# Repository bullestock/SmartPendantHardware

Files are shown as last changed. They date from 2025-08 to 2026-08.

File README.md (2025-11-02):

# Devtronic SmartPendant

This project allows controlling a grblHAL based CNC machine without a PC. It also makes work way more convenient.

This fork builds upon the original Devtronic/Nicolai Shlapunov project, which has a store here: https://devtronic.square.site/

I have no intentions to offer this version for sale, but all files are freely available. The changes compared to the original project are:

* Instead of a display with two FCC connectors this version uses a display with a single 2.54 mm pitch connector. This does mean that the pendant is a few millimetres thicker.
* The LEDs have been removed.
* Passives are 0603 instead of 0805.
* Screw terminals have been replaced with JST XH connectors.

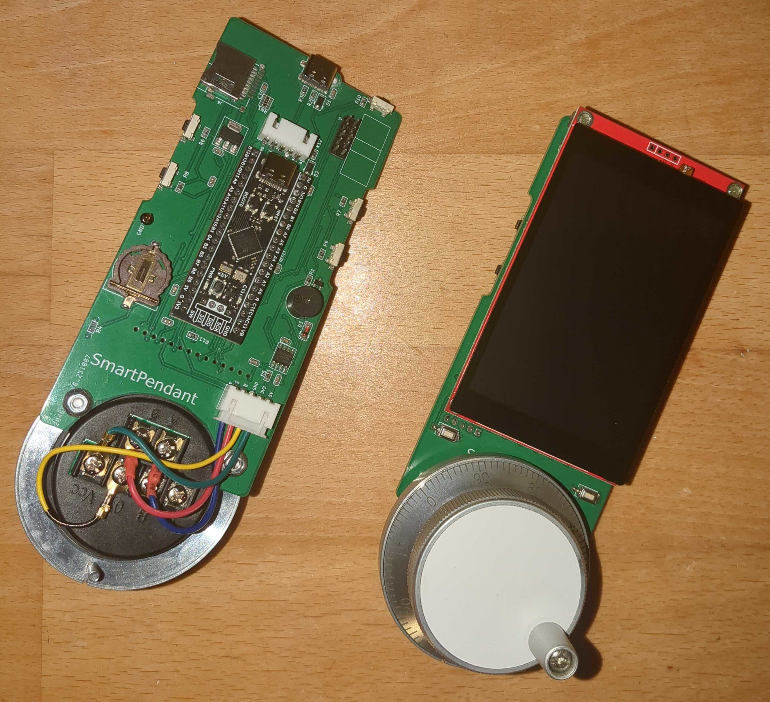
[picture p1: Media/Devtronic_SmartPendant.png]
Devtronic SmartPendant


# Firmware

Source code for this project can be found here: **https://github.com/bullestock/SmartPendantFirmware**

To load new firmware you can either use OpenOCD, or the [STM32CubeProgrammer](https://www.st.com/en/development-tools/stm32cubeprog.html).

## OpenOCD

For this you need an "ST-Link V2 mini" adapter, which can be obtained for a few dollars from AliExpress and other sites.

Connect the adapter and run this command:

    openocd -f interface/stlink.cfg -f target/stm32f4x.cfg -c "program SmartPendant.elf verify reset exit"

## STM32CubeProgrammer

Connect SmartPendant to PC using USB-C cable. Press and hold BOOT0 button, then short press NRST button, couple seconds later BOOT0 button can be released.
Open STM32CubeProgrammer. In top right corner choose "USB" from drop down list.
If field "Port" in "USB Configuration" show "No DFU detected" click update button near it.
Click "Connect" button - STM32CubeProgrammer should establish connection and show current device memory content.
Click "Open File" in left to corner, select firmware HEX file, then click "Download" button in top left corner.
When flashing is done, close STM32CubeProgrammer and short press NRST button on the Controller to restart it. 

**Note:** if flashing is successful, but firmware isn't work, check STM32CubeProgrammer log. If it says "sector 0000 does not exist" erasing operation wasn't successful and new firmware "merged"(write operation can only flip bits from 1 to 0) with old one. To fix this issue, press "eraser" button in bottom right corner and click "Ok" button in pop up window. After erasing is finished "Device memory" should show only FFFFFFFF. Flash new firmware after that. 

# Parts

To make this project yourself, you will need these essential parts:

* [WeAct BlackPill F411 25M HSE:](https://s.click.aliexpress.com/e/_DC6TlGd)
* [3.5" Display with touchscreen based on ILI9488 LCD controller and FT6236 touch controller](https://www.aliexpress.com/item/1005009339669149.html)
* [60 mm 6 pin 100 PPR handwheel](https://s.click.aliexpress.com/e/_DCFuJHr)
* [SMD connector for display](https://www.aliexpress.com/item/1005005194925318.html) (note that the connector must be aligned with the through holes, and that you need to remove the plastic part of the header on the display; see picture below).
* [Side button switches](https://www.aliexpress.com/item/1005003036287080.html)
* [Front button switches](https://www.aliexpress.com/item/1005007564864690.html)
* [USB C connector](https://www.aliexpress.com/item/1005008913274510.html)
* [Battery holder](https://www.aliexpress.com/item/4000648810345.html)
* [Buzzer](https://www.aliexpress.com/item/32949954569.html)
* The SD card footprint allows for two common sockets to be mounted.
* See the KiCAD files for additional components.

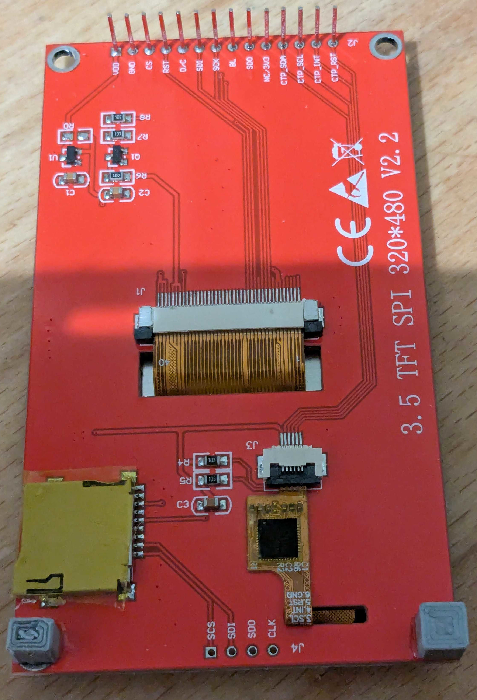
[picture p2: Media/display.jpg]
Preparing the display

Note the placement of the two display support pieces (glued to the PCB).

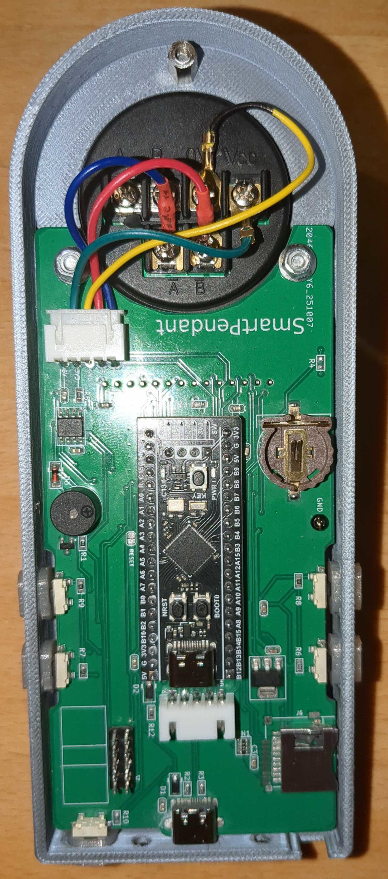
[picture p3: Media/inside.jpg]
PCB mounted in case

Note 8 mm threaded standoff on bottom encoder screw. Two printed spacers are mounted beneath the PCB.

## Case

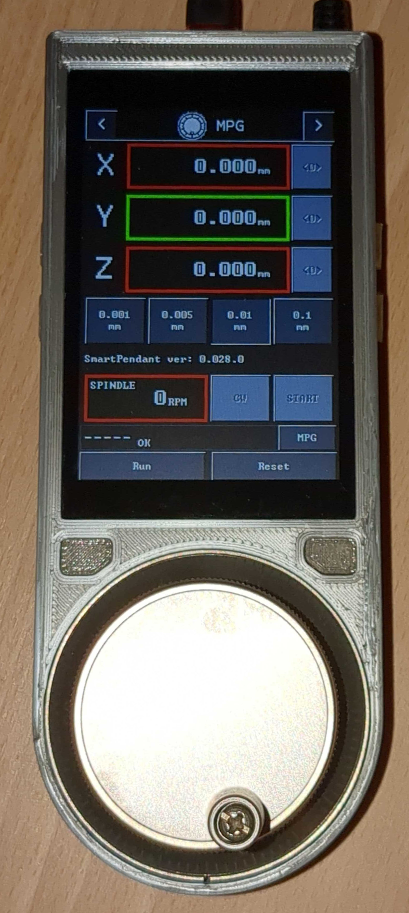
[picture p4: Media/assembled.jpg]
Assembled SmartPendant


3D_Print folder of this repo contain 3D files (OpenSCAD and STLs) of the case.

I printed the buttons in TPU filament.

## Dimensions

**160** mm x **65** mm x **24** mm (56 mm with handwheel and handle)

## Schematic

See the kicad directory.

## Firmware

Source code can be found [here](https://github.com/bullestock/SmartPendantFirmware)

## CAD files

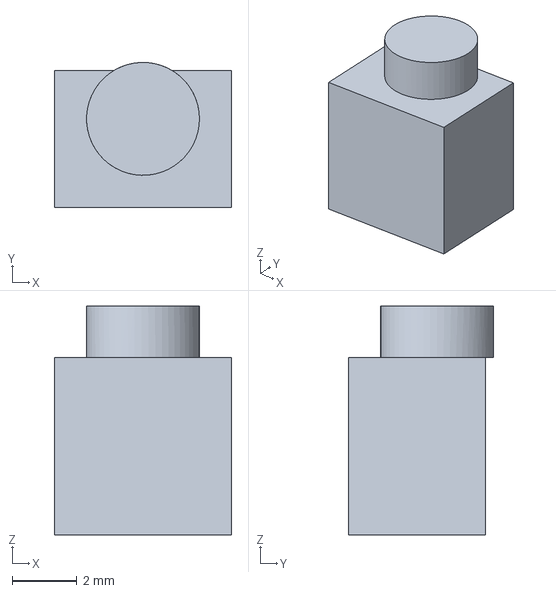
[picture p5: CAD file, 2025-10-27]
3D_Print/sp-display-spacer-2.step
5.50 x 4.50 x 7.10 mm

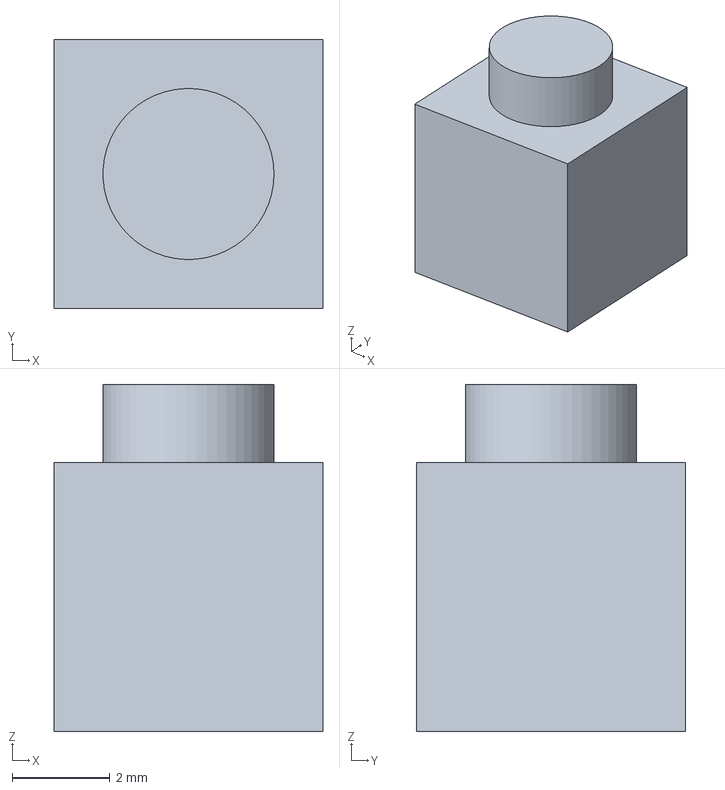
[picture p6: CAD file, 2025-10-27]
3D_Print/sp-display-spacer-1.step
5.50 x 5.50 x 7.10 mm

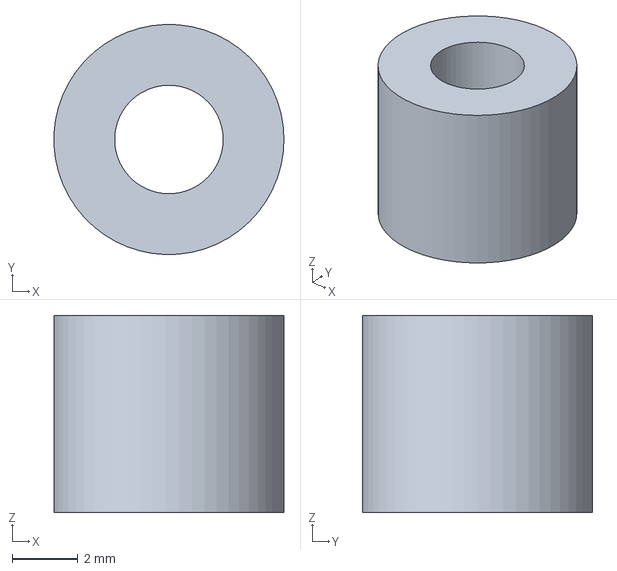
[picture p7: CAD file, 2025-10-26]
3D_Print/sp-pcb-spacer.step
6.99 x 7.00 x 6.00 mm

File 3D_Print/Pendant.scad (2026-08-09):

$fn=600;
//$fn=500;
//$fn=25;

//import("OBJ_PCB_Smart_Pendant.stl");

// Disable parts for fast update during development
FOR_PRINT = 1;
DRAW_BUTTON_HOLES = 1;
DEBUG_PORT = 0;

T = 2.4; // Case thickness
R = 2.6; // Case radius
W = 60; // Width(encoder & board)
L = 156+R*2; // Length(full length + two radiuses)
H = 20;

// Encoder tolerance
ENC_T = 0.4;

// Encoder rim height
ENC_RT = 6;

ENC_OFFSET = -5;
STANDOFF_C = 6+5.6-1.4; // For 8 mm hex standoff
BUTTON_OFFSET = -3;

BW = 60; // Board Width
BL = 126; // Board Length(from center of encoder to top edge)
BT = 1.6 + 2; // Board thickness
BZPOS = 4.4; // Board Z position if placed on table display face down
BUTZ = 7; // Button Z offset
SHZ = 8; // Screw hole Z offset

SW = 55.5; // Screen width
SH = 89.0; // Screen height
//SH = 88.8; // old
BZW = 51.5; // Bezel width
BZH = 78.0; // Bezel height
// DBL = 96; // Display Board Length

GLAND_W = 5.5;
GLAND_H = 5;

//ED = 4.2; // Distance betweeen encoder edge and screen glass
ED = BL - BW/2 - SH - (BW - SW)/2;

CP = 102.5; // MicroSD card placement

BOTTOM_H = 4; // Height of bottom piece
LOCK_H = 1.6; // Lock height


Top();
//Bottom();
//translate([75,0,0]) Bottom();
//translate([0, 0, H+BOTTOM_H]) rotate([0, 180, 0]) Bottom();

//Board();

// *******************************************************************
// ***   PCB   *******************************************************
// *******************************************************************
module PCB(H)
{
  color("purple") difference()
  {
    translate([0,0, BZPOS]) linear_extrude(height=H)
      polygon(points=[[-30,0],[-30,65],[-28.6,67.5],[-28.6,94],[-30,96.5],[-30,126],
                      [30,126],[30,96.5],[28.6,94],[28.6,67.5],[30,65],[30,0]]);
    translate([0,0,0]) cylinder(d=43, h=H);
  }
}

// *******************************************************************
// ***   Board   *****************************************************
// *******************************************************************
module Board()
{
  PCB(BT);
  translate([-57.2/2,73.2, BZPOS+BT+4]) rotate([0, 90, 0]) cylinder(d=3.5, h=57.2); // Down buttons
  translate([-57.2/2,88.3, BZPOS+BT+4]) rotate([0, 90, 0]) cylinder(d=3.5, h=57.2); // Up buttons
  // Top button
  translate([23.5,120,0])
  {
    color("black") translate([0,0.1, BZPOS+BT+4]) rotate([-90,0,0]) cylinder(d=3.5, h=5); // Up buttons
    color("silver") translate([-6.2/2,0, BZPOS+BT]) cube([6.2,4,6.2]);
  }
  // Face L buttons
  translate([23.4,28.3,0])
  {
    color("gold") translate([0,0, BZPOS-1.8]) cylinder(d=2, h=1.8); // Up buttons
    color("silver") translate([-5.08/2,-5.08/2, BZPOS-1.4]) cube([5.08,5.08,1.4]);
  }
  // Face R buttons
  translate([-23.5,28.4,0])
  {
    color("gold") translate([0,0, BZPOS-1.8]) cylinder(d=2, h=1.8); // Up buttons
    color("silver") translate([-5.08/2,-5.08/2, BZPOS-1.4]) cube([5.08,5.08,1.4]);
  }
}

// *******************************************************************
// ***   SideButtonRing   ********************************************
// *******************************************************************
module SideButtonRing(DO, DI, L, H)
{
  difference()
  {
    hull()
    {
      translate([-H/2,-L/2,0]) rotate([0, 90, 0]) cylinder(d=DO, h=H); // Up buttons
      translate([-H/2,+L/2,0]) rotate([0, 90, 0]) cylinder(d=DO, h=H); // Up buttons
    }
    hull()
    {
      translate([-H/2-1,-L/2,0]) rotate([0, 90, 0]) cylinder(d=DI, h=H+2); // Up buttons
      translate([-H/2-1,+L/2,0]) rotate([0, 90, 0]) cylinder(d=DI, h=H+2); // Up buttons
    }
  }
}

// *******************************************************************
// ***   Rotate functions   ******************************************
// *******************************************************************
function RotateX(X, Y, A) = X*cos(A) + Y*sin(A);
function RotateY(X, Y, A) = X*sin(A) + Y*cos(A);

// *******************************************************************
// ***   Button Hole   ***********************************************
// *******************************************************************
module ButtonHole(DFG, D)
{
    // Left button hole
    difference()
    {
        H = 3;
        R = W/2+H+D/2;

        BUTTON_LEN = 4.2;

        Y1 = (W/2+BUTTON_LEN-DFG) - ((W/2+BUTTON_LEN-DFG)-28.3)*2 + D/2; // Find symmetrical bottom distance
        X1 = sqrt(abs(Y1*Y1 - R*R));
        X2 = SW/2 - (SW/2-23.4)*2;// + D/2;
        Y2 = sqrt(abs(X2*X2 - R*R));
        
        hull()
        {
            // slanted corners
            translate([X1, Y1, -0.1]) cylinder(d=D, h=20);
            translate([X2, Y2, -0.1]) cylinder(d=D, h=20);
            // top right angle corner
            translate([SW/2-D/2, Y1, -0.1]) cylinder(d=D, h=20);
            // bottom corners
            translate([SW/2-D/2, W/2+BUTTON_LEN-DFG-D/2 + 0.8, -0.1]) cylinder(d=D, h=20);
            translate([X2, W/2+BUTTON_LEN-DFG-D/2 + 0.8, -0.1]) cylinder(d=D, h=20);
        }
        translate([0,0,-0.2]) cylinder(d=W+H*2, h=20);
    }
}
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

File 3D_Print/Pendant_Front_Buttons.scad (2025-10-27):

$fn = 600;

// First parameter - corner radius. It can be less than original one for clearence.
// Second parameter - Radius for lock, it may be greater than original
// Third parameter - length reduction(added to clearence gained by smaller first parameter)
translate([-15, 0, 0]) FrontButton(2.5, 3.6, 0.3);
mirror([1, 0, 0]) translate([-15, 0, 0]) FrontButton(2.5, 3.6, 0.3);

//Jig(2.5, 3.6, 0.3, 30);

// *******************************************************************
// ***   Button Hole   ***********************************************
// *******************************************************************
module FrontButton(DB, DL, LR)
{
  // All parameters from Pendant
  DFG = 2.8;
  D = 3;
  SW = 55.3; // Screen width
  SH = 88.9; // Screen height
  BW = 60; // Board Width
  BL = 126; // Board Length(from center of encoder to top edge)
  ED = BL - BW/2 - SH - (BW - SW)/2;
  W = 60; // Width(encoder & board)
  T = 2.4; // Case thickness
  
  H = 3;
  R = W/2+H+D/2;

  Y1 = (W/2+ED-DFG) - ((W/2+ED-DFG)-28.3)*2 + D/2; // Find symmetrical bottom distance
  X1 = sqrt(abs(Y1*Y1 - R*R));
  X2 = SW/2 - (SW/2-23.4)*2;// + D/2;
  Y2 = sqrt(abs(X2*X2 - R*R));

  skirt_h = 5.4 - 0.8;
  BH = skirt_h + 4.6 + 0.8;
  difference()
  {
    hull()
    {
      translate([X1-0.8, Y1, -0.1]) cylinder(d=DB, h=BH);
      translate([X2, Y2-0.5, -0.1]) cylinder(d=DB, h=BH);
      translate([SW/2-D/2 - LR + 0.3, Y1, -0.1]) cylinder(d=DB, h=BH);
      translate([SW/2-D/2 - LR + 0.3, W/2+ED-DFG-D/2,-0.1]) cylinder(d=DB, h=BH);
      translate([X2, W/2+ED-DFG-D/2, -0.1]) cylinder(d=DB, h=BH);
    }
  }
  difference()
  {
    hull()
    {
      translate([X1 - 1, Y1, -0.1]) cylinder(d=DL, h=skirt_h);
      translate([X2, Y2 - 0.5, -0.1]) cylinder(d=DL, h=skirt_h);
      translate([SW/2-D/2 - LR + 0.5,Y1,-0.1]) cylinder(d=DL, h=skirt_h);
      translate([SW/2-D/2 - LR + 0.5, W/2+ED-DFG-D/2,-0.1]) cylinder(d=DL, h=skirt_h);
      translate([X2,W/2+ED-DFG-D/2,-0.1]) cylinder(d=DL, h=skirt_h);
    }
  }
}

// *******************************************************************
// ***   Button Hole   ***********************************************
// *******************************************************************
module Jig(DB, DL, LR, HEIGHT)
{
  // All parameters from Pendant
  DFG = 2.8;
  D = 3;
  SW = 55.3; // Screen width
  SH = 88.9; // Screen height
  BW = 60; // Board Width
  BL = 126; // Board Length(from center of encoder to top edge)
  ED = BL - BW/2 - SH - (BW - SW)/2;
  W = 60; // Width(encoder & board)
  T = 2.4; // Case thickness
  
  H = 3;
  R = W/2+H+D/2;

  Y1 = (W/2+ED-DFG) - ((W/2+ED-DFG)-28.3)*2 + D/2; // Find symmetrical bottom distance
  X1 = sqrt(abs(Y1*Y1 - R*R));
  X2 = SW/2 - (SW/2-23.4)*2;// + D/2;
  Y2 = sqrt(abs(X2*X2 - R*R));

  difference()
  {
    hull()
    {
      translate([X1,Y1,-0.1]) cylinder(d=DB, h=HEIGHT);
      translate([X2,Y2,-0.1]) cylinder(d=DB, h=HEIGHT);
      translate([SW/2-D/2 - LR,Y1,-0.1]) cylinder(d=DB, h=HEIGHT);
      translate([SW/2-D/2 - LR,W/2+ED-DFG-D/2,-0.1]) cylinder(d=DB, h=HEIGHT);
      translate([X2,W/2+ED-DFG-D/2,-0.1]) cylinder(d=DB, h=HEIGHT);
    }
    translate([0,0,-0.2]) cylinder(d=W+H*2+(D-DB), h=H+0.4);
  }
}

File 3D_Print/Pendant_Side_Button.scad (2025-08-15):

$fn = 600;

SideButton(9.7, 5.6, 6.5); // 1
//SideButton(9, 5.4, 6.5); // 2

//Jig(9.2, 5.6, 6.5, 30);

// *******************************************************************
// ***   SideButton module   *****************************************
// *******************************************************************
module SideButton(L, DB, DL)
{
  // Total height
  BH = 6;
  skirt_height = 1.7;
  // Button
  hull()
  {
    translate([-(L-DB)/2, 0, 0]) cylinder(d=DB, h=BH);
    translate([+(L-DB)/2, 0, 0]) cylinder(d=DB, h=BH);
  }
  // Skirt
  hull()
  {
    translate([-(L-DB)/2, 0, 0]) cylinder(d=DL, h=skirt_height);
    translate([+(L-DB)/2, 0, 0]) cylinder(d=DL, h=skirt_height);
  }
}

// *******************************************************************
// ***   Jig module   ************************************************
// *******************************************************************
module Jig(L, DB, DL, H)
{
  // Button
  hull()
  {
    translate([-(L-DB)/2,0,0]) cylinder(d=DB, h=H);
    translate([+(L-DB)/2,0,0]) cylinder(d=DB, h=H);
  }
}

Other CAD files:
3D_Print/sp-display-spacer.step
kicad/frame.scad

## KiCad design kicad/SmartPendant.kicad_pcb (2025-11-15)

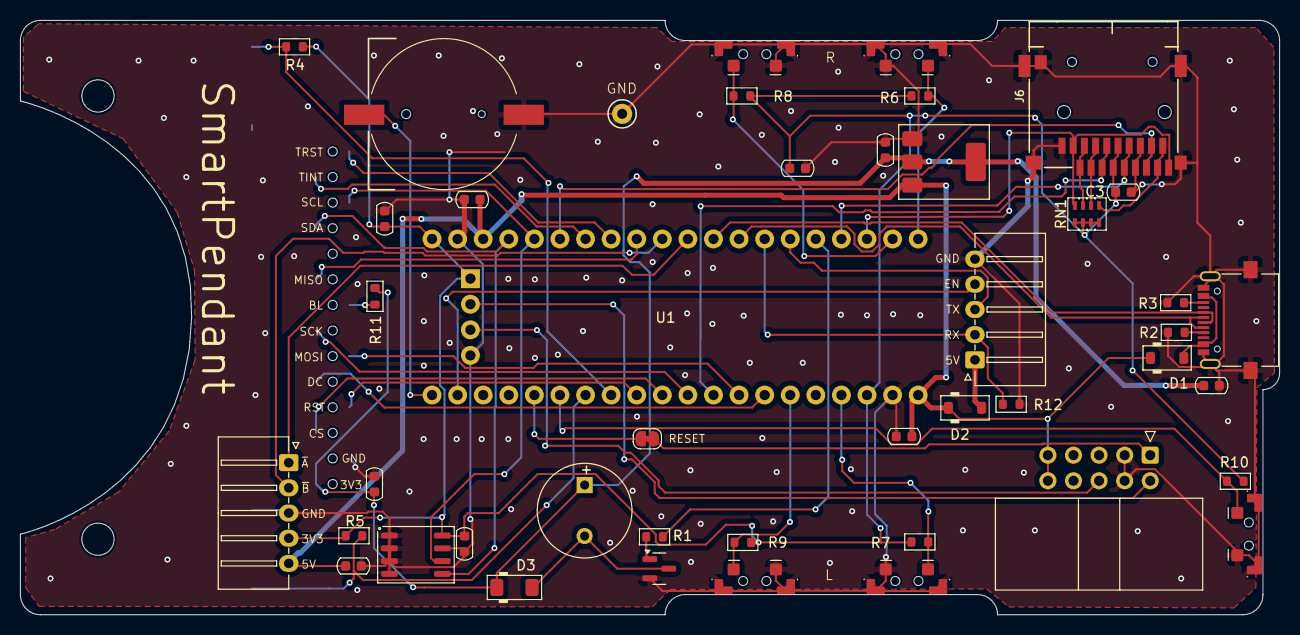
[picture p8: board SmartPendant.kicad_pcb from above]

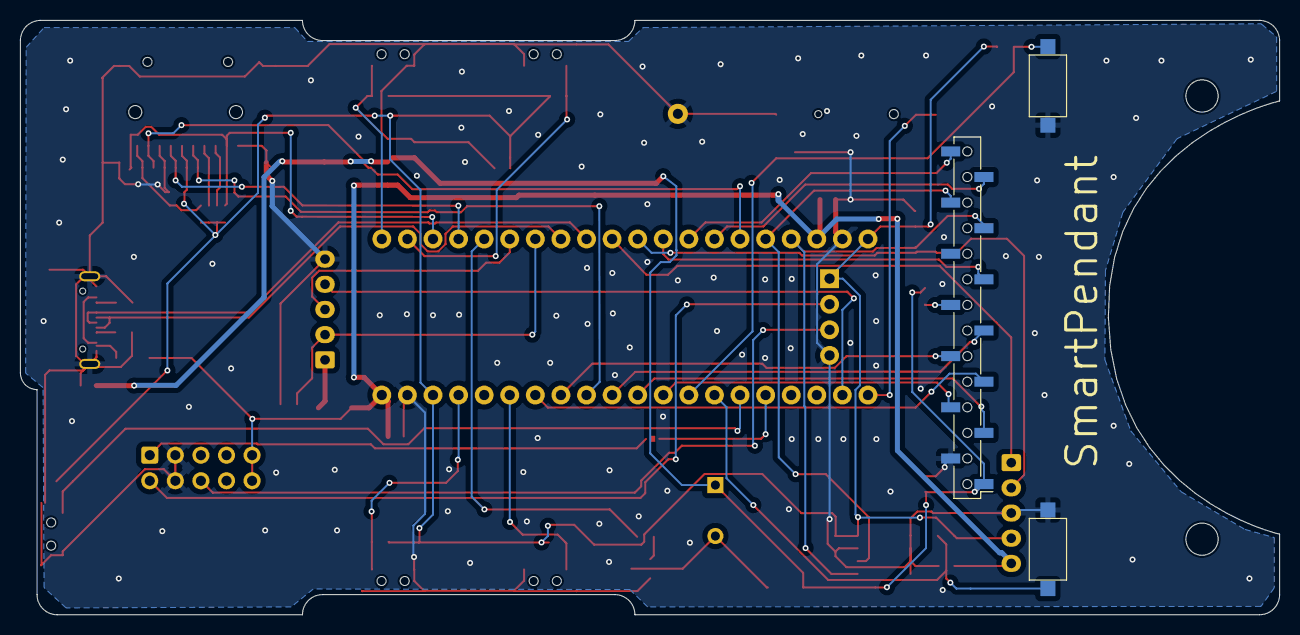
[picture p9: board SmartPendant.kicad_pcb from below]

Board: 2 copper layers, 125.0 x 59.0 mm, 49 parts (3 on the bottom side), 48 nets.

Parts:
BT1: CR1220; CR1220_Battery_Holder
BTN_L1: SPST; SW_SPST_CK_RS282G05A3
BTN_LD1: SPST; SMD_Push_Side_button_3x6x3.5mm
BTN_LU1: SPST; SMD_Push_Side_button_3x6x3.5mm
BTN_R1: SPST; SW_SPST_CK_RS282G05A3
BTN_RD1: SPST; SMD_Push_Side_button_3x6x3.5mm
BTN_RU1: SPST; SMD_Push_Side_button_3x6x3.5mm
BTN_USR1: SPST; SMD_Push_Side_button_3x6x3.5mm
BZ1: Buzzer; Buzzer_4.7x9.4mm
C1, C2, C3, C4, C5, C6, C7, C8, C9, C10: 1uF; C_0603_1608Metric
D1, D2: 1N5819; D_SOD-123
D3: 1N4148; D_MiniMELF
H1, H2: MountingHole; MountingHole_3.2mm_M3
J1: UART; JST_XH_S5B-XH-A_1x05_P2.50mm_Horizontal_Compact
J2: ST-LINK; IDC-Header_2x05_P2.54mm_Horizontal
J3: Encoder; JST_XH_S5B-XH-A_1x05_P2.50mm_Horizontal_Compact
J4: Display; PinSocket_1x14_P2.54mm_Vertical_SMD_Pin1Left_TH
J5: USB_C_Receptacle_USB2.0_16P; USB_C_Receptacle_AliExpress_16pin
J6: Micro_SD_Card_Det1; J_SD_Card-micro_dual
Q1: MMBT3904; SOT-23
R1: 470; R_0603_1608Metric
R2, R3: 5k1; R_0603_1608Metric
R4, R5, R6, R7, R8, R9, R10: 1kΩ; R_0603_1608Metric
R11: 0; R_0603_1608Metric
R12: 10kΩ; R_0603_1608Metric
RN1: 10k; R_Array_Concave_4x0603
RST1: SB_402; SolderJumper-2_P1.3mm_Bridged_RoundedPad1.0x1.5mm
TP1: GND; TestPoint_Keystone_5000-5004_Miniature
U1: WEACT BLACKPILL F4X1; BlackPill_STLINK
U2: AMS1117-3.3; SOT-223-3_TabPin2
U3: MB85RC256VPNF-G-JNERE1; SOP-8_3.9x4.9mm_P1.27mm

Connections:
+3.3V: BZ1.1 (+), C6.1, C7.1, C8.1, D3.1 (K), J4.1, R11.1, U2.2 (VO)
+5V: C2.1, C9.1, C10.1, D1.1 (K), D2.1 (K), J2.9, J2.10, J3.5, U1.18 (5V), U1.40 (5V), U2.3 (VI)
BAT: BT1.1 (+), U1.21 (VBAT)
BTN_LD: BTN_RD1.1, R9.2, U1.35 (PB1)
BTN_LU: BTN_RU1.2, R7.2, U1.37 (PB10)
BTN_RD: BTN_LD1.2, R8.2, U1.2 (PB13)
BTN_RU: BTN_LU1.1, R6.2, U1.1 (PB12)
BUZZER: R1.1, U1.5 (PA8)
ENC_A: J3.1, U1.10 (PA15)
ENC_B: J3.2, U1.11 (PB3)
GND: BT1.2 (-), BTN_L1.2, BTN_LD1.1, BTN_LD1.SH (B), BTN_LU1.2, BTN_LU1.SH (B), BTN_R1.2, BTN_RD1.2, BTN_RD1.SH (B), BTN_RU1.1, BTN_RU1.SH (B), BTN_USR1.1, BTN_USR1.SH (B), C1.2, C2.2, C3.2, C4.2, C5.2, C6.2, C7.2, C8.2, C9.2, C10.2, J1.5, J2.3, J2.4, J3.3, J4.2, J5.A1 (GND), J5.A12 (GND), J5.B1 (GND), J5.B12 (GND), J5.S1 (SHIELD), J6.6 (VSS), J6.10 (SHIELD), Q1.2 (E), R2.2, R3.2, R12.2, TP1.1, U1.19 (GND), U1.39 (GND), U1.44 (GND), U2.1 (GND), U3.1 (A0), U3.2 (A1), U3.3 (A2), U3.4 (VSS), U3.7 (WP)
LCD_CS: J4.3, U1.30 (PA4)
LCD_DC: J4.5, U1.34 (PB0)
LCD_MISO: J4.9, U1.12 (PB4)
LCD_MOSI: J4.6, U1.33 (PA7)
LCD_RST: J4.4, U1.29 (PA3)
LCD_SCK: J4.7, U1.31 (PA5)
LEFT_BTN: BTN_R1.1, R5.2, U1.27 (PA1)
MPG_EN: J1.4, U1.22 (PC13)
unnamed: BZ1.2 (-), D3.2 (A), Q1.3 (C)
unnamed: D1.2 (A), J5.A4 (VBUS), J5.A9 (VBUS), J5.B4 (VBUS), J5.B9 (VBUS)
unnamed: D2.2 (A), J1.1
unnamed: J2.1, RST1.2 (B)
unnamed: J4.8, R11.2
unnamed: J5.A5 (CC1), R2.1
unnamed: J5.B5 (CC2), R3.1
unnamed: J6.8 (DAT1), RN1.5 (R4.2)
unnamed: J6.1 (DAT2), RN1.7 (R2.2)
unnamed: J6.2 (DAT3/CD), RN1.6 (R3.2)
unnamed: Q1.1 (B), R1.2
RIGHT_BTN: BTN_L1.1, R4.2, U1.28 (PA2)
RST: RST1.1 (A), U1.25 (~RESET)
SCL: J4.12, U1.16 (PB8), U3.6 (SCL)
SDA: J4.11, U1.17 (PB9), U3.5 (SDA)
SDIO_CD: J6.9 (DET), RN1.8 (R1.2), U1.3 (PB14)
SDIO_CK: J6.5 (CLK), U1.4 (PB15)
SDIO_CMD: J6.3 (CMD), U1.32 (PA6)
SDIO_D0: J6.7 (DAT0), U1.15 (PB7)
SWCLK: J2.6, U1.43 (SWSCK)
SWDIO: J2.2, U1.42 (SWDIO)
TOUCH_INT: J4.13, U1.14 (PB6)
TOUCH_RST: J4.14, U1.13 (PB5)
UART_RX: J1.2, R12.1, U1.7 (PA10)
UART_TX: J1.3, U1.6 (PA9)
USB_DN: J5.A7 (D-), J5.B7 (D-), U1.8 (PA11)
USB_DP: J5.A6 (D+), J5.B6 (D+), U1.9 (PA12)
USR_BTN: BTN_USR1.2, R10.2, U1.26 (PA0)
VCC: C1.1, C3.1, C4.1, C5.1, J3.4, J6.4 (VDD), R4.1, R5.1, R6.1, R7.1, R8.1, R9.1, R10.1, RN1.1 (R1.1), RN1.2 (R2.1), RN1.3 (R3.1), RN1.4 (R4.1), U1.20 (3V3), U1.38 (3V3), U1.41 (3.3V), U3.8 (VDD)

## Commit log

2025-05-31 Add raw import from EasyEDA.
    [SmartPendant.kicad_sch]
2025-05-31 Fix cosmetics.
    [SmartPendant.kicad_sch]
2025-05-31 Update schematic to match V1.3.
    [SmartPendant.kicad_sch]
2025-05-31 Add footprints.
    [SmartPendant.kicad_sch]
2025-06-23 Make side switch footprint.
    [SmartPendant.kicad_sch]
2025-07-16 Do not generate raft.
    [Pendant.scad]
2025-07-16 Remove last traces of raft nonsense.
    [Pendant.scad]
2025-07-16 More cleanup, adapt to new display.
    [Pendant.scad]
2025-07-17 Fix encoder screw hole.
    [Pendant.scad]
2025-07-17 Make room for display, remove LED holes.
    [Pendant.scad]
2025-07-17 Remove LEDs.
    [Pendant.stl, SmartPendant.kicad_sch]
2025-07-17 Fix bottom.
    [Pendant.scad]
2025-07-18 Fix bottom display support.
    [Pendant.scad]
2025-07-18 Remove unnecessary bottom button.
    [Pendant.scad]
2025-07-18 Add new display connector.
    [Pendant.stl, SmartPendant.kicad_sch]
2025-07-30 Change most symbols to proper KiCad ones.
    [SmartPendant.kicad_sch]
2025-07-30 Update rest of power symbols.
    [SmartPendant.kicad_sch]
2025-07-30 Fix display hole size and position.
    [Pendant.scad]
2025-07-30 Add footprints, initial outline.
    [Pendant.scad, Pendant.stl, SmartPendant.kicad_pcb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]
2025-08-01 Fix some footprint issues.
    [SmartPendant.kicad_pcb, SmartPendant.kicad_sch]
2025-08-02 Update BlackPill footprint.
    [SmartPendant.kicad_pcb]
2025-08-02 Fix some component positions.
    [SmartPendant.kicad_pcb]
2025-08-02 Move components around.
    [SmartPendant.kicad_pcb]
2025-08-02 Fix ERC violations.
    [SmartPendant.kicad_pcb, SmartPendant.kicad_sch]
2025-08-02 Use angle JST connectors.
    [SmartPendant.kicad_pcb, SmartPendant.kicad_sch]
2025-08-02 Optimize component placement.
    [SmartPendant.kicad_pcb]
2025-08-03 Tweak layout.
    [Pendant.scad, SmartPendant.kicad_pcb]
2025-08-04 Adjust display height.
    [Pendant.scad]
2025-08-04 Remove generated file.
    [Pendant.stl]
2025-08-04 Increase heigth again.
    [Pendant.scad]
2025-08-04 Try to fix front button holes.
    [Pendant.scad]
2025-08-04 Add PCB supports.
    [Pendant.scad]
2025-08-04 Adjust size.
    [Pendant_Side_Button.scad]
2025-08-04 Add PCB support.
    [Pendant.scad]
2025-08-04 Fix positioning issues.
    [SmartPendant.kicad_pcb]
2025-08-04 Fix DRC error.
    [SmartPendant.kicad_pcb]
2025-08-04 Set provisional footprint for buzzer.
    [SmartPendant.kicad_pcb, SmartPendant.kicad_sch]
2025-08-04 Enlarge front button holes.
    [Pendant.scad]
2025-08-05 Make front buttons fit holes.
    [Pendant_Back.stl, Pendant_Cable_Relief.stl, Pendant_Front_Button_Jig.stl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]
2025-08-05 Fix bottom button holes position.
    [Pendant.scad]
2025-08-05 Fix lock height.
    [Pendant.scad]
2025-08-05 Fix outline.
    [SmartPendant.kicad_pcb]
2025-08-08 More button tweaks.
    [Pendant.scad]
2025-08-08 Make PCB wider.
    [SmartPendant.kicad_pcb]
2025-08-09 Increase height.
    [Pendant_Front_Buttons.scad]
2025-08-09 Change front buttons.
    [SmartPendant.kicad_pcb, SmartPendant.kicad_sch]
2025-08-09 Adapt height for new tactile button.
    [Pendant_Front_Buttons.scad]
2025-08-09 Add 10 mm standoff on encoder screw.
    [Pendant.scad]
2025-08-15 Correct last footprints.
    [Pendant.scad, SmartPendant.kicad_pcb, SmartPendant.kicad_sch]
2025-08-15 Start routing.
    [SmartPendant.kicad_pcb]
2025-08-15 Adjust skirt height.
    [Pendant_Side_Button.scad]
2025-08-15 Fix bottom standoff height.
    [Pendant.scad]
2025-08-15 Route some more.
    [SmartPendant.kicad_pcb, SmartPendant.kicad_sch]
2025-08-16 More routing.
    [SmartPendant.kicad_pcb]
2025-08-16 Complete routing.
    [SmartPendant.kicad_pcb]
2025-08-16 Add ground planes.
    [SmartPendant.kicad_pcb]
2025-08-16 Adjust silk screen.
    [SmartPendant.kicad_pcb]
2025-09-13 Fix orientation of display connector.
    [SmartPendant.kicad_pcb]
2025-09-14 Add GND test point.
    [SmartPendant.kicad_pcb, SmartPendant.kicad_sch]
2025-09-14 Add labels.
    [SmartPendant.kicad_pcb]
2025-09-14 Invert A, B.
    [SmartPendant.kicad_pcb]
2025-09-18 Use resistor array; make references consecutive.
    [SmartPendant.kicad_pcb, SmartPendant.kicad_sch]
2025-09-19 Optimize SD card footprint and routing.
    [SmartPendant.kicad_pcb]
2025-09-20 Add dual footprint for SD-card socket.
2025-09-22 Use dual SD-card footprint.
    [SmartPendant.kicad_pcb, SmartPendant.kicad_sch]
2025-10-05 Increase width of power tracks, add stitching vias.
    [SmartPendant.kicad_pcb]
2025-10-18 Add stencil.
    [SmartPendant.kicad_pcb]
2025-10-25 Add missing SD card pad. Swap left/right side buttons.
    [SmartPendant.kicad_pcb, SmartPendant.kicad_sch, frame.scad]
2025-10-25 Swap left and right front buttons.
    [SmartPendant.kicad_pcb, SmartPendant.kicad_sch]
2025-10-25 Move buzzer inwards.
    [SmartPendant.kicad_pcb]
2025-10-26 Add spacers; tweak case.
    [Pendant.scad, sp-display-spacer.step, sp-pcb-spacer.step]
2025-10-27 Move top switch.
    [SmartPendant.kicad_pcb]
2025-10-27 Fix length.
    [Pendant_Front_Buttons.scad]
2025-10-27 Fix skirt size.
    [Pendant_Front_Buttons.scad]
2025-10-27 Make buttons move again, oops.
    [Pendant_Front_Buttons.scad]
2025-10-27 Crop picture; add PCB side supports.
    [Pendant.scad]
2025-10-27 Add picture and note about display.
    [sp-display-spacer-1.step, sp-display-spacer-2.step]
2025-10-28 Increase height slightly.
    [sp-display-spacer-1.step, sp-display-spacer-2.step]
2025-10-28 Fix lock size.
    [Pendant.scad]
2025-11-01 Revert "Increase height slightly."
    This reverts commit 1170e3b782fb1b672919bf61e8fbac57eba1ba4c.
    [sp-display-spacer-1.step, sp-display-spacer-2.step]
2025-11-01 Adjust lock sizes.
    [Pendant.scad]
2025-11-15 Add display labels.
    [SmartPendant.kicad_pcb]
2026-08-09 Save swap buttons patch.
    [Pendant.scad]
